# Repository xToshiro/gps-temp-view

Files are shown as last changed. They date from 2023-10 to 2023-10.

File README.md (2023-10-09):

# AirTemp_View
# Arduino Project for Urban Heat Island Monitoring with ESP32

This is an Arduino project developed to monitor urban heat islands in the city. It uses an ESP32 with 30 pins, a BME280 temperature, pressure, and humidity sensor, a u-blox NEO-6M GPS module, and an SD Card module to collect georeferenced data of temperature, pressure, and humidity along the route and save this data to a memory card.

## Objective

The objective of this project is to install the device in a vehicle to collect environmental data such as temperature, pressure, and humidity while the vehicle moves through the city. The data is recorded along with GPS location information, allowing for the mapping of urban heat islands in the city.
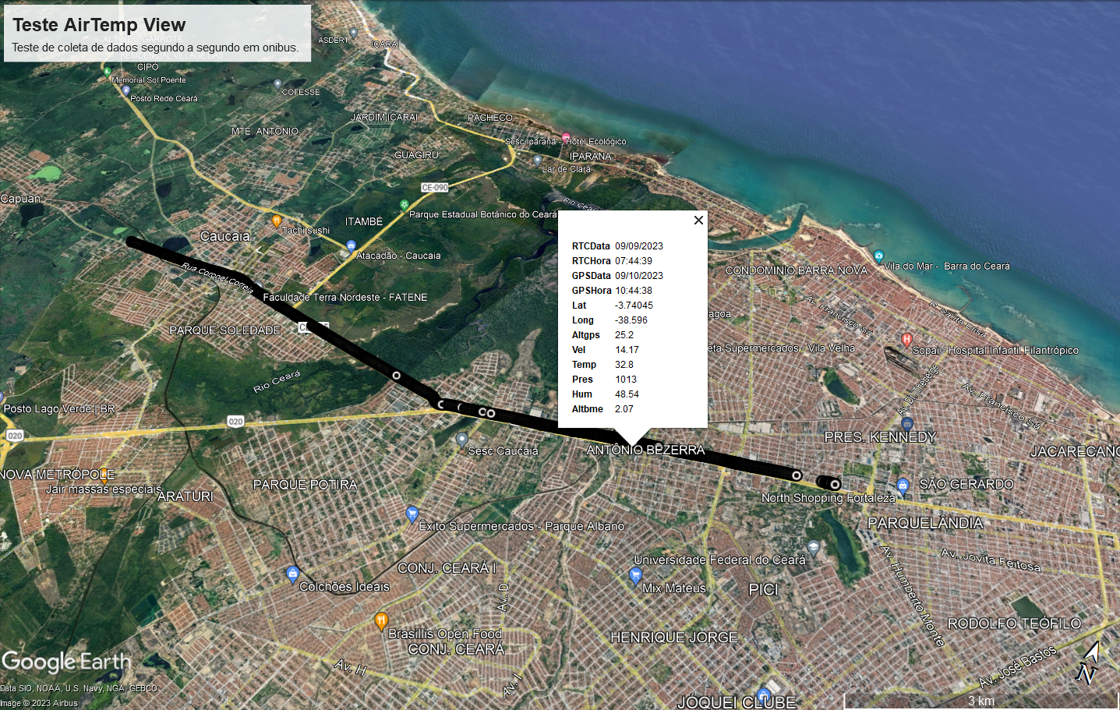
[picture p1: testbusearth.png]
testbusearth


## Required Components

- ESP32 with 30 pins
- BME280 temperature, pressure, and humidity sensor
- u-blox NEO-6M GPS module
- SD Card module
- Prototyping board (protoboard)
- Power supply compatible with the ESP32
- Cables and wires for connections
- MicroSD card for data storage

## Assembly

1. Connect the ESP32, BME280 sensor, NEO-6M GPS module, and SD Card module to the prototyping board according to the appropriate connection scheme.
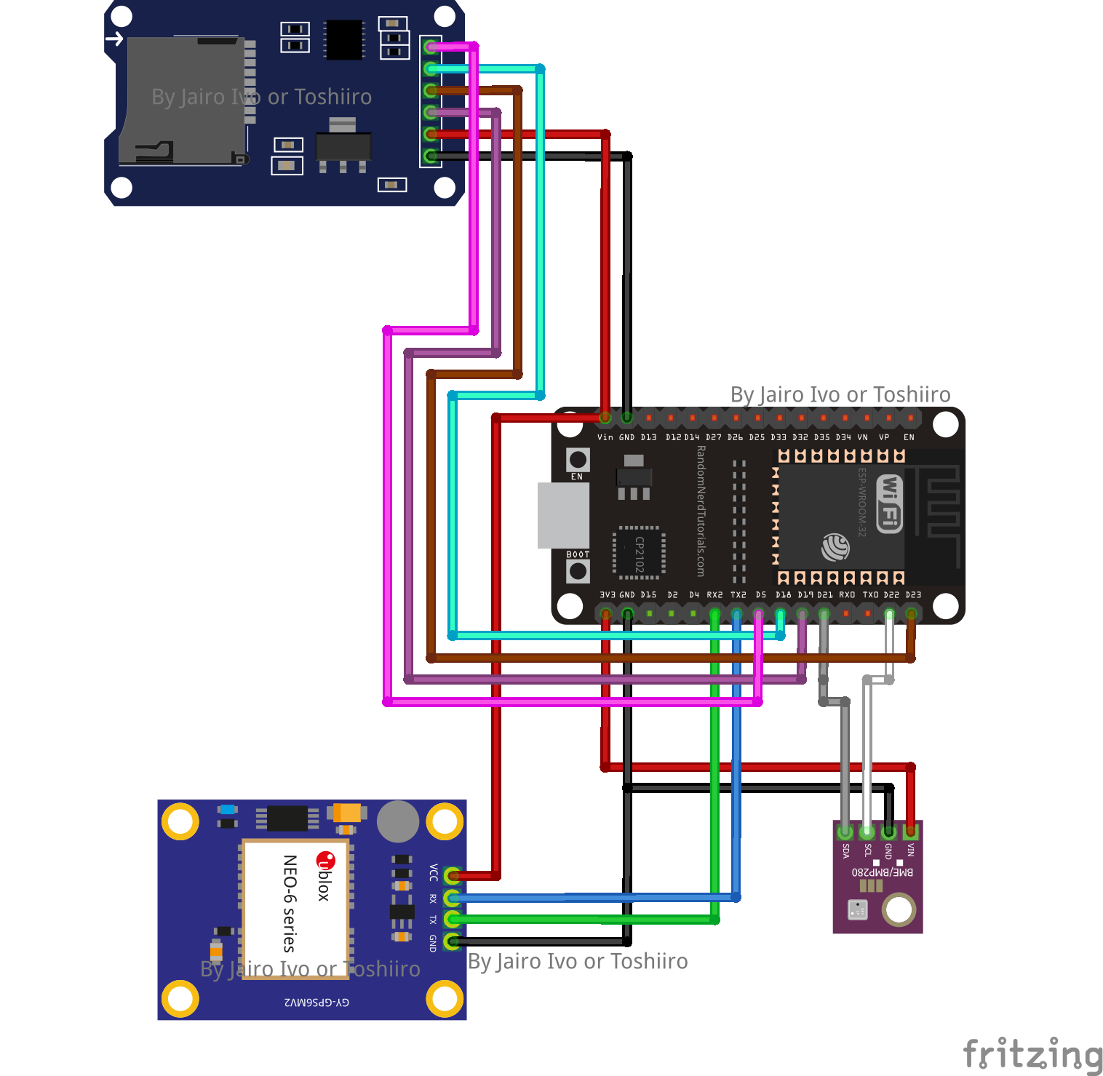
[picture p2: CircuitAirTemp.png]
CircuitAirTemp

2. Power the ESP32 with the power supply and ensure all components are properly connected.

## Configuration

Before uploading the Arduino code to the ESP32, make sure to set up the Arduino IDE development environment with the necessary libraries for the components used (BME280, NEO-6M, SD Card, etc.). You will also need to configure the GPS module's network settings, such as baud rate, protocol, etc.

## Usage

1. Upload the Arduino code to the ESP32 using the Arduino IDE.

2. Place the device in the vehicle according to the necessary guidelines to ensure good GPS reception and accurate environmental data collection.

3. Power on the device and wait for it to start collecting data.

4. The collected data will be stored on the microSD card in a specific format, including date, time, latitude, longitude, temperature, pressure, and humidity information.

## Data Visualization

You can use data visualization software such as spreadsheets or geographic mapping software to analyze the collected data and map urban heat islands in the city.

# Project Update Log

## Version 4.0 - AirTemp View (Current Version)

### Release Date: 08/10/2023

#### Summary:

In the latest update, Version 4.0, named "AirTemp View," we have introduced significant improvements to the project's data collection process. Now, data is collected every second, providing more granular information for urban heat island monitoring.

#### What's New:

1. **Real-Time Clock (RTC) Synchronization:** With Version 4.0, we have implemented real-time clock (RTC) synchronization. The ESP32's internal RTC is now synchronized with the date and time data from the GPS module. This synchronization ensures accurate timekeeping during data collection.

2. **Second-Level Data Collection:** Data is now collected at the second level of granularity. This increased frequency allows for more precise tracking of environmental conditions. The ESP32's internal RTC is used as a synchronization factor for the seconds, ensuring that data is consistently collected every second.
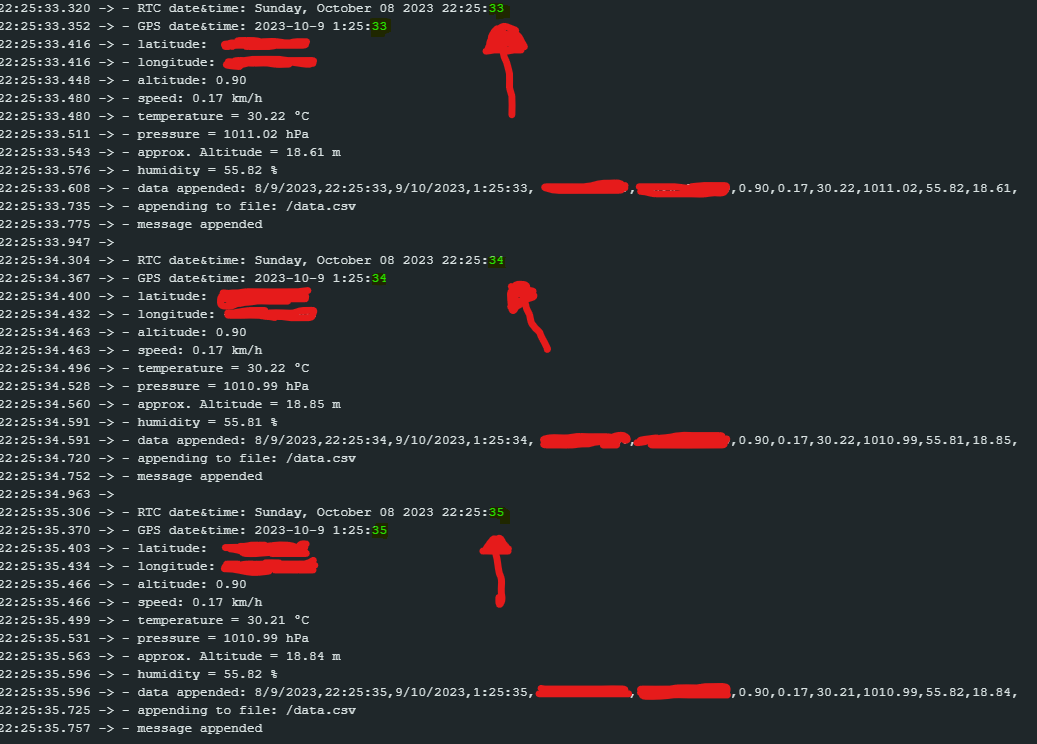
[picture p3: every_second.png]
EverySecond

3. **Backup GPS Synchronization:** Users now have the flexibility to use a backup GPS, such as a mobile application, for synchronization. Data can be synchronized later by aligning the date and time from the backup GPS with the collected data.

#### How to Upgrade:

To take advantage of these new features, please update your project code to Version 4.0. Refer to the updated documentation for instructions on how to implement RTC synchronization and utilize the enhanced data collection capabilities.

#### Notes:

Ensure that you are familiar with the changes introduced in this update and make any necessary adjustments to your project setup for optimal data collection and analysis.

---

**Note:** Always ensure the accuracy of GPS data for reliable synchronization, and consider privacy and data security when handling collected information.

## Contributions

Contributions to this project are welcome! Feel free to create issues or send pull requests with improvements.

## License

This project is distributed under the [GNU General Public License v3.0 (GPL-3.0)](LICENSE).

---

**Note:** Ensure that you are familiar with local regulations and privacy laws when using this monitoring device. It is essential to respect the privacy and rights of citizens.

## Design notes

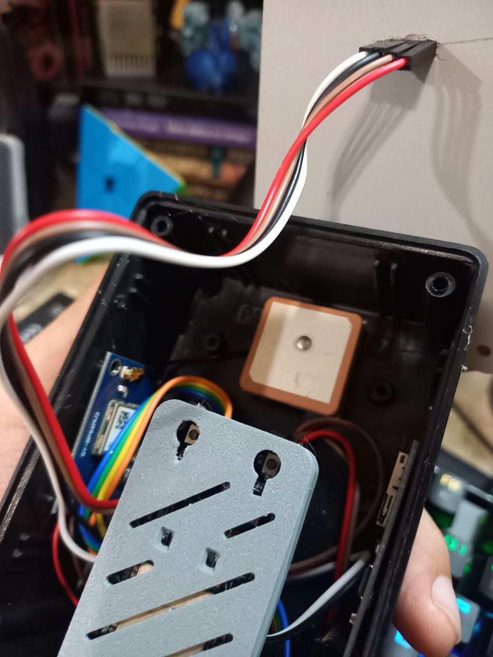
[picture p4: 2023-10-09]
airtempv4/project/v4(2).jpg

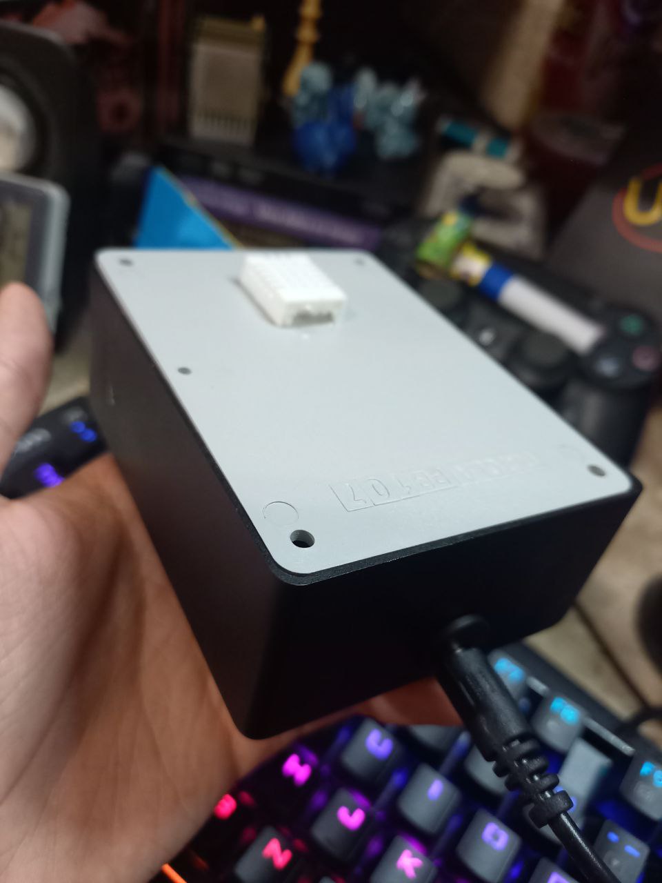
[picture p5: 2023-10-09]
airtempv4/project/v4(4).jpg

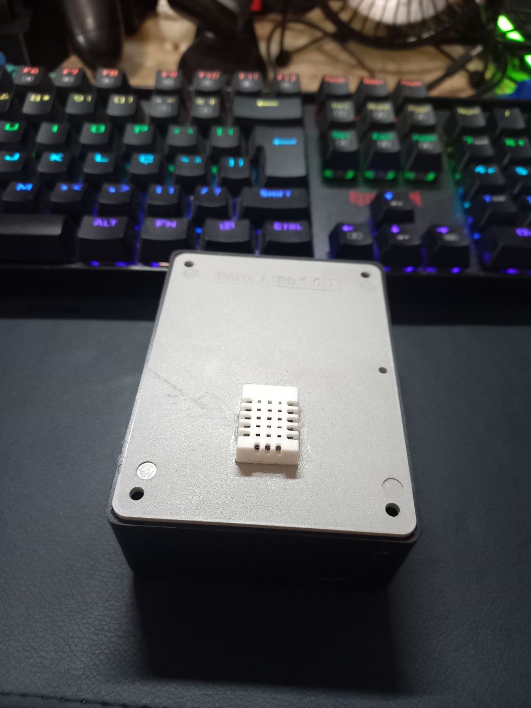
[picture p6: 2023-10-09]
airtempv4/project/v4.jpg

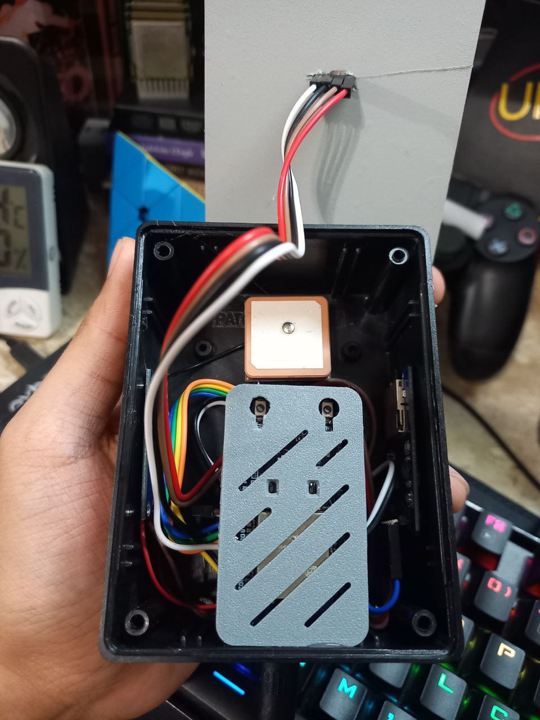
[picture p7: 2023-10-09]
airtempv4/project/v4(1).jpg

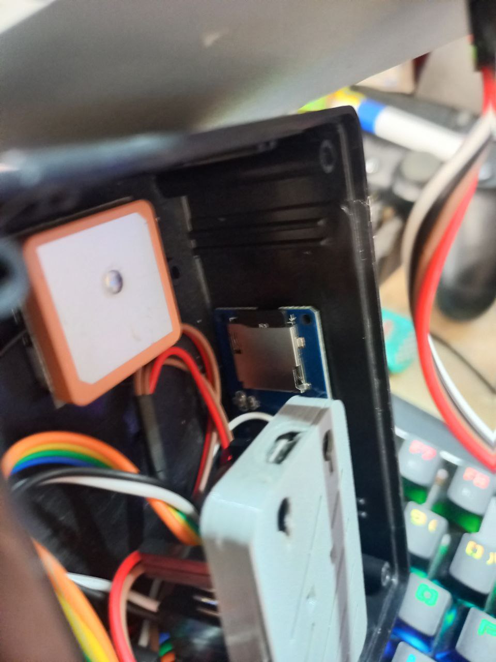
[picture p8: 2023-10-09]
airtempv4/project/v4(3).jpg

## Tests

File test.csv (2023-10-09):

RTCData | RTCHora | GPSData | GPSHora | Lat | Long | Altgps | Vel | Temp | Pres | Hum | Altbme
09/09/2023 | 07:19:32 | 09/10/2023 | 10:19:29 | -3.73511 | -38.67262333 | 0 | 0 | 30.77 | 1011.66 | 54.53 | 13.25
09/09/2023 | 07:19:33 | 09/10/2023 | 10:19:33 | -3.7350705 | -38.67261817 | 46.3 | 0.09 | 30.77 | 1011.67 | 54.64 | 13.09
09/09/2023 | 07:19:34 | 09/10/2023 | 10:19:34 | -3.7350695 | -38.67261917 | 46 | 0.02 | 30.78 | 1011.66 | 54.69 | 13.25
09/09/2023 | 07:19:35 | 09/10/2023 | 10:19:35 | -3.73506933 | -38.67261933 | 45.9 | 0.22 | 30.77 | 1011.63 | 54.54 | 13.5
09/09/2023 | 07:19:36 | 09/10/2023 | 10:19:36 | -3.73507067 | -38.67261933 | 45.7 | 0.17 | 30.78 | 1011.67 | 54.74 | 13.18
09/09/2023 | 07:19:37 | 09/10/2023 | 10:19:37 | -3.73507167 | -38.67262033 | 45.8 | 0.07 | 30.79 | 1011.66 | 54.7 | 13.24
09/09/2023 | 07:19:38 | 09/10/2023 | 10:19:38 | -3.73507 | -38.67262067 | 45.3 | 0 | 30.78 | 1011.7 | 54.53 | 12.93
09/09/2023 | 07:19:39 | 09/10/2023 | 10:19:39 | -3.735069 | -38.67262067 | 44.9 | 0.07 | 30.78 | 1011.67 | 54.47 | 13.17
09/09/2023 | 07:19:40 | 09/10/2023 | 10:19:40 | -3.73506933 | -38.67261967 | 44.6 | 0.06 | 30.79 | 1011.69 | 54.5 | 13.03
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

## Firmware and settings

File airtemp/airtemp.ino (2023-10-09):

#include <Adafruit_Sensor.h>
#include <Adafruit_BME280.h>
#include <Wire.h>
#include <TinyGPSPlus.h>
#include <SoftwareSerial.h>
#include <SD.h>
#include <SPI.h>
#include <ESP32Time.h>

#define SEALEVELPRESSURE_HPA (1013.25)

//ESP32Time rtc;
ESP32Time rtc(-10800);  // offset in seconds GMT+1


const int ledVerdePin = 2;
const int ledVermelhoPin = 12;
const int ledAmareloPin = 15;
// Definição dos pinos RX e TX para o GPS
static const int RXPin = 16, TXPin = 17;

static const uint32_t GPSBaud = 9600;

File dataFile;

// Tempo de atualização do GPS em milissegundos
const unsigned long intervaloAtualizacao = 1000;
unsigned long ultimaAtualizacao = 0;

// Inicialização do objeto GPS
TinyGPSPlus gps;
// Inicia o objeto do sensor de temperatura
Adafruit_BME280 bme;

// Inicialização do objeto SoftwareSerial
SoftwareSerial ss(RXPin, TXPin);

String dataMessage;

unsigned long dia = 0;
unsigned long mes = 0;
unsigned long ano = 0;
unsigned long hora = 0;
unsigned long minuto = 0;
unsigned long segundo = 0;

char gpslat = 0;
char gpslong = 0;

char latitudeStr[15];
char longitudeStr[15];

double gpsalt = 0;
float gpsvel = 0;


// Variaveis de leitura dos sensores
//BME
float temp = 0;
float hum = 0;
float pres = 0;
float alt = 0;

// Função para ligar o LED Verde
void ligarLedVerde() {
  digitalWrite(ledVerdePin, HIGH);
  digitalWrite(ledVermelhoPin, LOW);
  digitalWrite(ledAmareloPin, LOW);
}

// Função para ligar o LED Vermelho
void ligarLedVermelho() {
  digitalWrite(ledVerdePin, LOW);
  digitalWrite(ledVermelhoPin, HIGH);
  digitalWrite(ledAmareloPin, LOW);
}

void ligarLedAmarelo() {
  digitalWrite(ledVerdePin, LOW);
  digitalWrite(ledVermelhoPin, LOW);
  digitalWrite(ledAmareloPin, HIGH);
}

void rtcSyncWithGps() {

  // This sketch displays information every time a new sentence is correctly encoded.
  while (ss.available() > 0)
    if (gps.encode(ss.read()))
      displayInfo();

  if (millis() > 5000 && gps.charsProcessed() < 10)
  {
    Serial.println(F("No GPS detected: check wiring."));
    while(true);
  }
}


void gpsprint() {
  Serial.print("Data: ");
  Serial.print(gps.date.month());
  Serial.print("/");
  Serial.print(gps.date.day());
  Serial.print("/");
  Serial.print(gps.date.year());
  Serial.print(" Hora: ");
  Serial.print(gps.time.hour());
  Serial.print(":");
  Serial.print(gps.time.minute());
  Serial.print(":");
  Serial.print(gps.time.second());
  Serial.print(" Latitude: ");
  Serial.print(gps.location.lat(), 6);
  Serial.print(" Longitude: ");
  Serial.print(gps.location.lng(), 6);
  Serial.print(" Altitude: ");
  Serial.print(gps.altitude.meters());
  Serial.print("m");
  Serial.print(" Velocidade: ");
  Serial.print(gps.speed.kmph());
  Serial.println("km/h");
}

void setup() {
  // Inicialização dos pinos dos LEDs
  pinMode(ledVerdePin, OUTPUT);
  pinMode(ledVermelhoPin, OUTPUT);
  pinMode(ledAmareloPin, OUTPUT);
  ligarLedVermelho();
  delay(1000);
  ligarLedAmarelo();
  delay(1000);
  ligarLedVerde();
  delay(1000);
  // Inicialização da comunicação serial com o monitor serial
  Serial.begin(115200);

  // Inicialização da comunicação serial com o GPS
  ss.begin(GPSBaud);

  // Verifica se o GPS está conectado corretamente
  unsigned long startTime = millis();
  while (millis() - startTime < 5000) {
    if (ss.available()) {
      // GPS conectado corretamente
      ligarLedVerde();
      Serial.println("GPS conectado corretamente.");
      delay(5000);
      break;
    }
  }

  if (!ss.available()) {
    // GPS não encontrado

    ligarLedVermelho();
    delay(500);
    Serial.println("GPS não encontrado ou falha na conexão.");
  }

  if (!bme.begin(0x76, &Wire)) {
    Serial.println("Could not find a valid BME280 sensor, check wiring!");
    while (1)
      ;
  }

  initSDCard();
  checkSDFile();  // Checa o arquivo data.csv no cartão de memoria ou cria se ele não existir
}

void bmeRead() {
  if (!bme.begin(0x76)) {
    //bmeLogSum += 1;
    //bmeStatus = false;
    //Serial.print("DHT ERROR! ");
  } else {
    temp = bme.readTemperature();
    hum = bme.readHumidity();
    pres = bme.readPressure();
    alt = bme.readAltitude(SEALEVELPRESSURE_HPA);
    //bmeStatus = true;
    //bmeSampleCount++;
    //Serial.print("SHT OK! ");
  }
}

void gpsRead() {
  // Verifica se há dados disponíveis na porta serial do GPS
  while (ss.available() > 0)
    // Lê os dados do GPS
    if (gps.encode(ss.read())) {
      // Verifica se os dados do GPS são válidos
      if (gps.location.isValid()) {
        saveData();
        // Atualiza a cada intervalo definido
        if (millis() - ultimaAtualizacao > intervaloAtualizacao) {
          ultimaAtualizacao = millis();
          // Imprime os dados no monitor serial
          gps.encode(ss.read());

          mes = gps.date.month();
          dia = gps.date.day();
          ano = gps.date.year();
          hora = gps.time.hour();
          minuto = gps.time.minute();
          segundo = gps.time.second();
          //gpslat = gps.location.lat();
          //gpslong = gps.location.lng();

          dtostrf(gps.location.lat(), 12, 8, latitudeStr);
          dtostrf(gps.location.lng(), 12, 8, longitudeStr);

          Serial.println(gps.altitude.meters());
          gpsalt = gps.altitude.meters();
          gpsvel = gps.speed.kmph();
          bmeRead();
          delay(500);
          ligarLedVerde();
        }
      } else {
        // Dados inválidos do GPS
        Serial.println("Dados inválidos do GPS!");
        //delay(1000);
        // Ligar o LED Vermelho
        ligarLedAmarelo();
      }
    }
}

void loop() {
  
}

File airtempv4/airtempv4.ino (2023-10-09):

//Coded by Jairo Ivo

#include <Adafruit_Sensor.h>
#include <Adafruit_BME280.h>
#include <TinyGPS++.h>
#include <ESP32Time.h>
#include <SD.h>
#include <SPI.h>
#include <Wire.h>

#define SEALEVELPRESSURE_HPA (1013.25)

#define LED 2

// ESP32Time rtc;
ESP32Time rtc(-10800);  // offset in seconds GMT-3

#define GPS_BAUDRATE 9600  // the default baudrate of NEO-6M is 9600

TinyGPSPlus gps;  // the TinyGPS++ object

String dataMessage;  // save data to sdcard

File dataFile;

// Starts the temperature sensor object
Adafruit_BME280 bme;

// Internal RTC Variables
int rtcdia, rtcmes, rtcano, rtchora, rtcminuto, rtcsegundo{ 0 };
// GPS Variables
int gpsdia, gpsmes, gpsano, gpshora, gpsminuto, gpssegundo{ 0 };
float gpslat, gpslong{ 0 };
char latitudeStr[15];
char longitudeStr[15];
double gpsalt = 0;
float gpsvel = 0;
// Sensor reading variables
// BME
float temp, hum, pres, alt{ 0 };

int gpsUpdate = 0; // Informs if the gps was updated on the last data

void setup() {
  Serial.begin(9600);
  Serial2.begin(GPS_BAUDRATE);

  Serial.println(F("AirTemp View - Coded by Jairo Ivo"));

  pinMode(LED, OUTPUT);

  initSDCard();
  checkSDFile();  // Check the data.csv file on the memory card or create it if it does not exist

  Serial.println(F("Initiating synchronization of the internal RTC with the gps!"));
  delay(500);
  while (rtc.getYear() < 2001) {
    Serial.println(F("."));
    rtcSyncWithGps();
    //delay(50);
  }

  if (!bme.begin(0x76, &Wire)) {
    delay(500);
    Serial.println("Couldn't find the BME280 sensor, check the wires!");
    while (1)
      ;
  }
}

void loop() {
  //delay(500);
  if (Serial2.available() > 0) {
    if (gps.encode(Serial2.read())) {
      digitalWrite(LED, LOW);
      if (gps.location.isValid()) {
        dtostrf(gps.location.lat(), 12, 8, latitudeStr);
        dtostrf(gps.location.lng(), 12, 8, longitudeStr);
        gpsUpdate = 1;
        if (gps.altitude.isValid()) {
          gpsalt = (gps.altitude.meters());
        } else {
          Serial.println(F("- alt: INVALID"));
          delay(150);
        }
      } else {
        Serial.println(F("- location: INVALID"));
        delay(150);
      }
      if (gps.speed.isValid()) {
        gpsvel = (gps.speed.kmph());
      } else {
        Serial.println(F("- speed: INVALID"));
        delay(150);
      }
      if (gps.date.isValid() && gps.time.isValid()) {
        gpsano = (gps.date.year());
        gpsmes = (gps.date.month());
        gpsdia = (gps.date.day());
        gpshora = (gps.time.hour());
        gpsminuto = (gps.time.minute());
        gpssegundo = (gps.time.second());
      } else {
        Serial.println(F("- gpsDateTime: INVALID"));
        delay(150);
      }
      //Serial.println();
    }
  }
  if ((rtc.getSecond()) != rtcsegundo) {
    digitalWrite(LED, HIGH);
    Serial.print(F("- RTC date&time: ")); Serial.println(rtc.getTime("%A, %B %d %Y %H:%M:%S"));  // (String) returns time with specified format
    rtcmes = rtc.getMonth(); rtcdia = rtc.getDay(); rtcano = rtc.getYear(); rtchora = rtc.getHour(true); rtcminuto = rtc.getMinute(); rtcsegundo = rtc.getSecond();

    Serial.print(F("- GPS date&time: ")); Serial.print(gpsano); Serial.print(F("-")); Serial.print(gpsmes); Serial.print(F("-")); Serial.print(gpsdia); Serial.print(F(" "));
    Serial.print(gpshora); Serial.print(F(":")); Serial.print(gpsminuto); Serial.print(F(":")); Serial.println(gpssegundo);
    Serial.print(F("- latitude: ")); Serial.println(latitudeStr);
    Serial.print(F("- longitude: ")); Serial.println(longitudeStr);
    Serial.print(F("- altitude: ")); Serial.println(gpsalt);
    Serial.print(F("- speed: ")); Serial.print(gpsvel); Serial.println(F(" km/h"));

    temp = bme.readTemperature();
    hum = bme.readHumidity();
    pres = (bme.readPressure() / 100.0F);
    alt = (bme.readAltitude(SEALEVELPRESSURE_HPA));

    Serial.print("- temperature = "); Serial.print(temp); Serial.println(" °C");
    Serial.print("- pressure = "); Serial.print(pres); Serial.println(" hPa");
    Serial.print("- approx. Altitude = "); Serial.print(alt); Serial.println(" m");
    Serial.print("- humidity = "); Serial.print(hum); Serial.println(" %");

    saveData();
    gpsUpdate = 0;
    Serial.println();
  }
}

void rtcSyncWithGps() {
  if (Serial2.available() > 0) {
    //delay(150);
    if (gps.encode(Serial2.read())) {
      delay(150);
      Serial.print(F("- GPS date&time: "));
      if (gps.date.isValid() && gps.time.isValid()) {
        Serial.print(gps.date.year()); Serial.print(F("-")); Serial.print(gps.date.month()); Serial.print(F("-")); Serial.print(gps.date.day()); Serial.print(F(" ")); 
        Serial.print(gps.time.hour()); Serial.print(F(":")); Serial.print(gps.time.minute()); Serial.print(F(":")); Serial.println(gps.time.second());
        rtc.setTime((gps.time.second()), (gps.time.minute()), (gps.time.hour()), (gps.date.day()), (gps.date.month()), (gps.date.year()));  // 17th Jan 2021 15:24:30
        //rtc.setTime(1609459200);  // 1st Jan 2021 00:00:00
        //rtc.offset = 7200; // change offset value
        Serial.print(F("- RTC date&time: ")); Serial.println(rtc.getTime("%A, %B %d %Y %H:%M:%S"));  // (String) returns time with specified format
        // formating options  http://www.cplusplus.com/reference/ctime/strftime/
      } else {
        Serial.println(F("No valid date and time data!"));
      }
      Serial.println();
    }
  }
  if (millis() > 5000 && gps.charsProcessed() < 10)
    Serial.println(F("No valid gps data: check connection"));
}

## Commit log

2023-10-09 feat: Implement real-time clock synchronization for second-level data collection
    [CircuitAirTemp.fzz]
2023-10-09 Tests & Modifications
    [CircuitAirTemp.fzz, test.csv]
